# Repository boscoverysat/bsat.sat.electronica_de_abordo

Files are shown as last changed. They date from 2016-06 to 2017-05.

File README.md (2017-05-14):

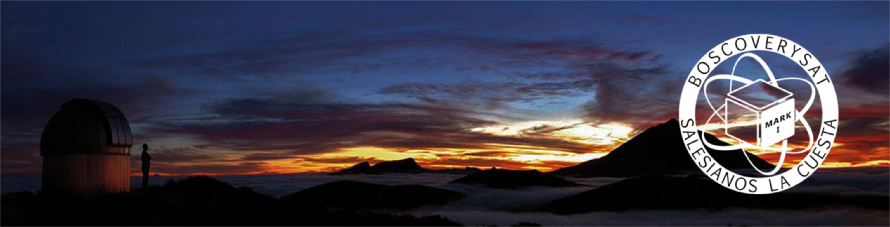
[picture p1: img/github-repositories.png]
Github header


# SAT Electrónica de Abordo

### Este repositorio ha sido descontinuado.

La información relativa a los elementos electrónicos del satélite podrán encontrarse en los siguientes enlaces:

- [Onboard Computer (OBC)](https://github.com/boscoverysat/bsat.sat.electronica.onboard_computer)
- [Electric Power System (EPS)](https://github.com/boscoverysat/bsat.sat.electronica.electric_power_system)
- [Communications (COMM)](https://github.com/boscoverysat/bsat.sat.electronica.communications)
- [Librerías](https://github.com/boscoverysat/bsat.sat.electronica.librerias)

### Licencia

Creaive Commons 4.0 logo (http://creativecommons.org/licenses/by-nc-sa/4.0/)

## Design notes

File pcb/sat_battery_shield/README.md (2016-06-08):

# SAT Battery Shield

## Resumen

Esta sección del repositorio contiene el circuito electrónico y el diseño de placa de circuito impreso para el sistema de alimentación del satélite.

El actual diseño electrónico se ha llevado a cabo mediante el software **KiCAD**.

## Contenido de la Shield

La PCB cuanta con unas dimensiones de 77 x 77 mm, realizada en base de fibra de vidrio y una única capa de cobre, disponiendo de cuatro orificios
de fijación, para el chasis del satélite, ubicados en las esquinas de la placa.

Actualmente, el diseño de este elemento se encuentra desarrollado para que sea capaz de alojar dos baterías recargables del tipo `18650`, por una tensión
nominal de **3,7V** y una intensidad de **5.000mAh**.

La placa tiene capacidad para conectar a ella cuatro parejas de placas solares, conectadas en serie entre ellas y posteriormente en paralelo en la propia
PCB. Esto nos permite contar con niveles de tensión de entre 8VDC y 11,50VDC, con una intensidad máxima de 50 mA, cada pareja de placas solares.

Para el sistema de recarga de baterías y alimentación de la electrónica de abordo, se han implementado dos módulos de recarga de baterías basados en
el circuito **TP4056**.

El objetivo de emplear este tipo de dispositivo era el de conectarlos en serie para poder proporcionar energía suficiente a la electrónica del satélite.

Además de lo indicado hasta el momento, la placa cuenta con un interruptor que nos permite encender y apagar el satélite de manera manual. En un futuro,
esta funcionalidad será empleada para implementar el sistema **RBF** ( *Remove Before Flight* ) así como los sistemas de conexión en el momento del
despliegue del satélite.

## Fallos detectados

Actualmente tenemos un fallo de alimentación dado que, una vez conectados los módulos `TP4056`, el segundo de ellos, al detectar un nivel de tensión
superior a los 4VDC en la salida del mismo (nivel proveniente del primer módulo que está conectado en serie con éste), deja de funcionar, proporcionando
a la salida de la placa, un nivel de tensión correspondiente al proporcionado únicamente por una de las baterías.

## Propuestas de mejora

- Rediseñar la electrónica de la placa con el objeto de implementar reguladores de tensión basados en los dispositivos **78L09** así como en el regulador de carga **MAX1873**.
- Proporcionar lineas de test para el registro del nivel de tensión proporcionado por las caras del satélite.
- Proporcionar lineas de test para el registro del nivel de tensión disponible en cada una de las baterías.

#### Diseño PCB

Diseño de PCB

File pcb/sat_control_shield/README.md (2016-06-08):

# SAT Control Shield

## Resumen

Esta sección del repositorio contiene el circuito electrónico y el diseño de placa de circuito impreso para el sistema de control del satélite.

El actual diseño electrónico se ha llevado a cabo mediante el software **KiCAD** e incluye en una misma placa, el núcleo de procesamiento del
satélite (formado por un Arduino Nano v3.0), los sensores de inercia y orientación, así como un único sensor de temperatura, los pines necesarios
para la conexión de cuatro sensores de intensidad luminosa y el módulo de transmisión RF a 433MHz.

## Contenido actual de la Shield

La PCB cuenta con unas dimensiones de 77 x 77 mm, realizada en base de fibra de vidrio y una única capa de cobre, disponiendo de cuatro orificios
de fijación, para el chasis del satélite, ubicados en las esquinas de la placa.

Actualmente la placa cuenta con una alimentación simple que proviene desde la shield de alimentación. De este modo, a la entrada de la placa disponemos
de un nivel de tensión de entre 7,5VDC y 8,4VDC, dependiendo del nivel de carga que tengan las baterías.

Con este nivel de voltaje se proporciona energía directamente a la unidad de control del satélite, formada por el Arduino Nano v3.0. A partir de él,
empleamos las salidas estabilizadas de 5VDC y 3,3VDC para alimentar al resto de elementos del circuito.

De este modo, el giroscopico (`HPU6000`), el acelerómetro (`HMC5883L`), el sensor de temperatura (`HTU21D`) y los sensores de luminosidad (`BH1750`) se
encuentran alimentados a 3,3VDC.

Por otro lado, el transmisor de RF (`CDT-88`) y el multiplexor de I2C (`74HC4052E`) se encuentran alimentados a 5VDC.

Todos los sensores presentes en la placa, se comunican con el Arduino a través del bus I2C. Por esta razón y dado que en el diseño se emplean múltiple
sensores del mismo modelo que vienen con la dirección de comunicación fijada por hardware, ha sido necesario emplear el circuito integrado `74HC4052E`,
encargado de multiplexar la señal SDA del I2C.

**NOTA:** La **multiplexación** de la señal **SDA** del bus **I2C** mediante el circuito integrado `74HC4052E` aún se encuentra en **fase experimental**.

## Fallos detectados

Aún no se han detectado fallos para el diseño actual.

## Propuestas de mejora

- Confirmar el correcto funcionamiento de la multiplexación del canal SDA del bus I2C mediante el uso del circuito integrado `74HC4052E`.
- Multiplexar la señal SDA para los sensores de intensidad luminosa.
- Multiplexar la señal SDA para los sensores de temperatura.
- Obtener lecturas de los niveles de tensión proporcionados por las placas solares dispuestas en las caras del satélite.
- Obtener lecturas de los niveles de tensión proporcionados por las baterías del sistema de alimentación.

#### Diseño PCB

Diseño de PCB

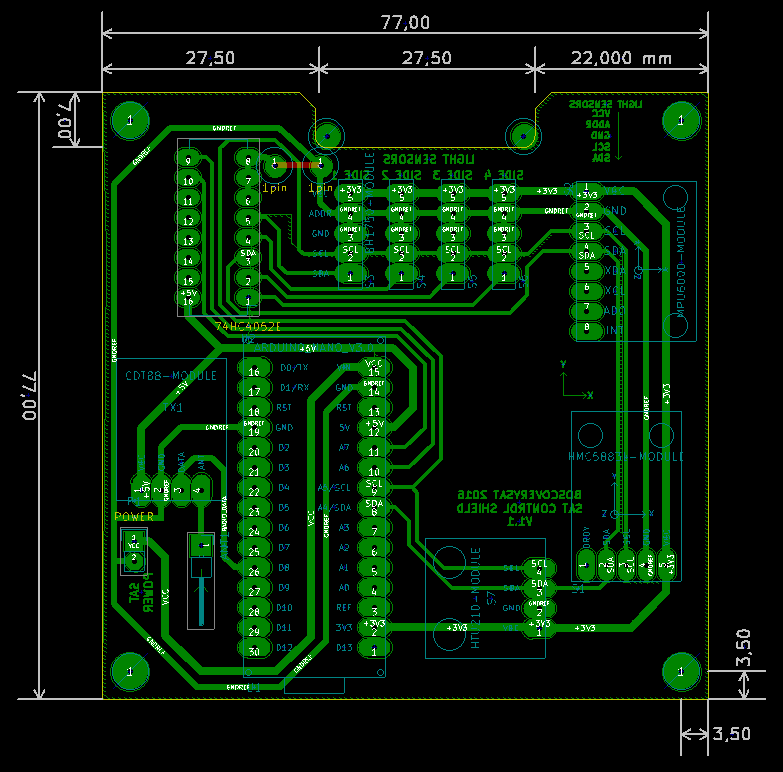
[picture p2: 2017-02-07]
pcb/sat_control_shield/img/Sat Control Shield - PCB - v2.0.png

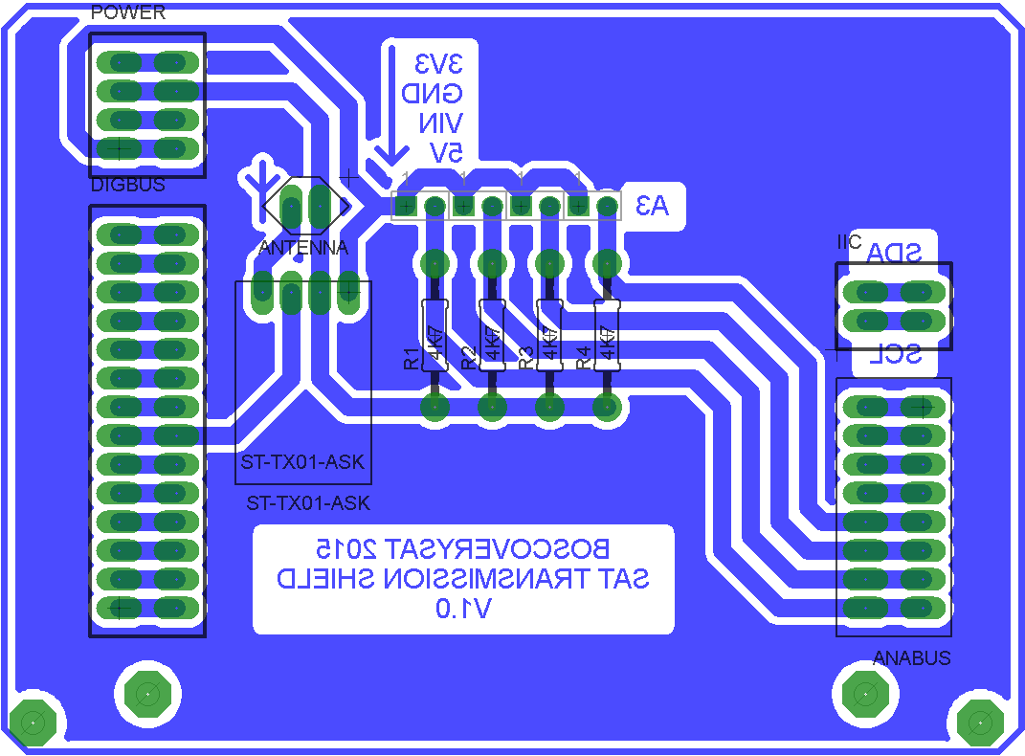
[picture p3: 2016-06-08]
pcb/sat_transmission_shield/img/sat_transmission_shield.png

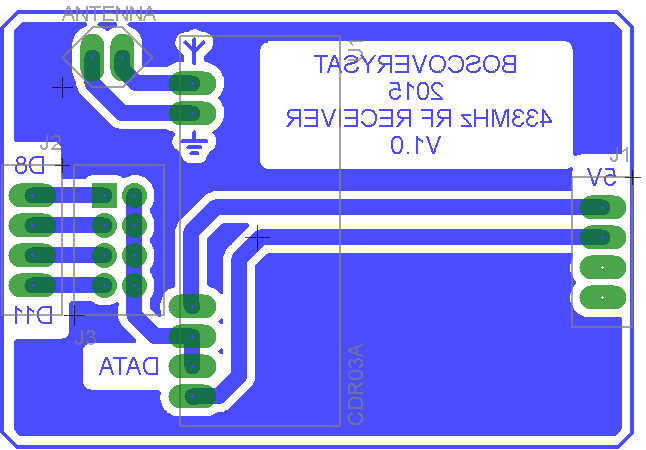
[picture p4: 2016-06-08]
pcb/receptor_rf_430mhz/img/430mhz_rf_receiver.png

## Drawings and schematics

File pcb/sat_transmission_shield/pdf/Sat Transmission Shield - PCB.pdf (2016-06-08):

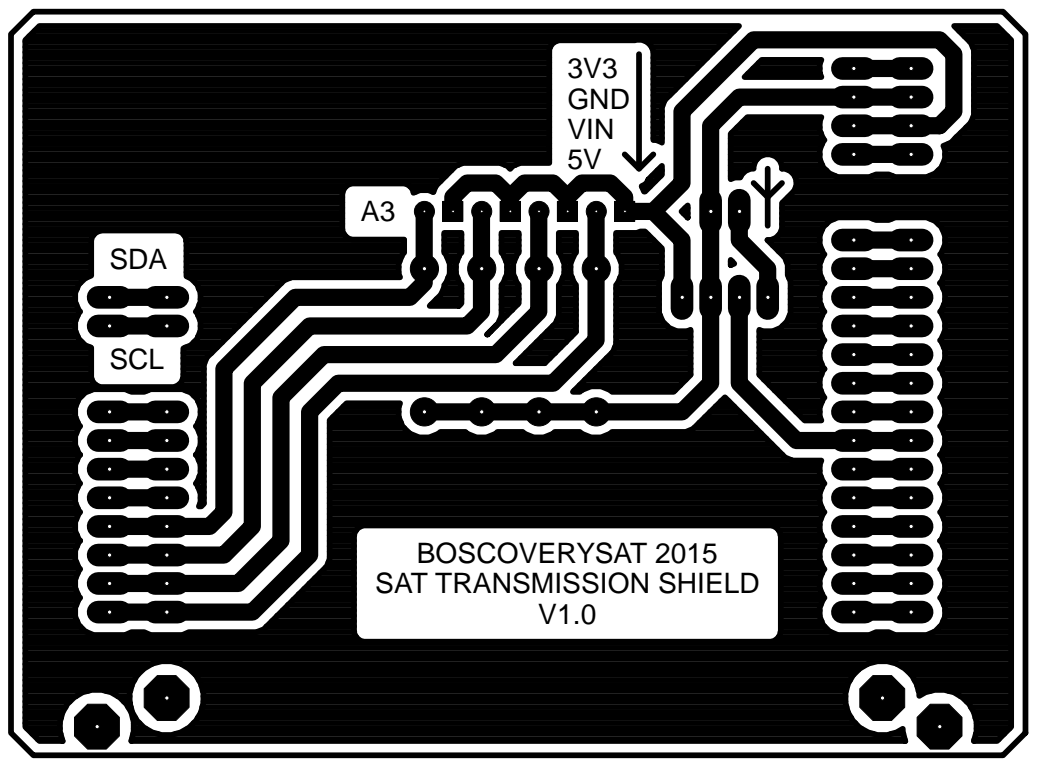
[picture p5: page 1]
3V3 GND VIN 5V; SCL; SDA

BOSCOVERYSAT 2015
SAT TRANSMISSION SHIELD

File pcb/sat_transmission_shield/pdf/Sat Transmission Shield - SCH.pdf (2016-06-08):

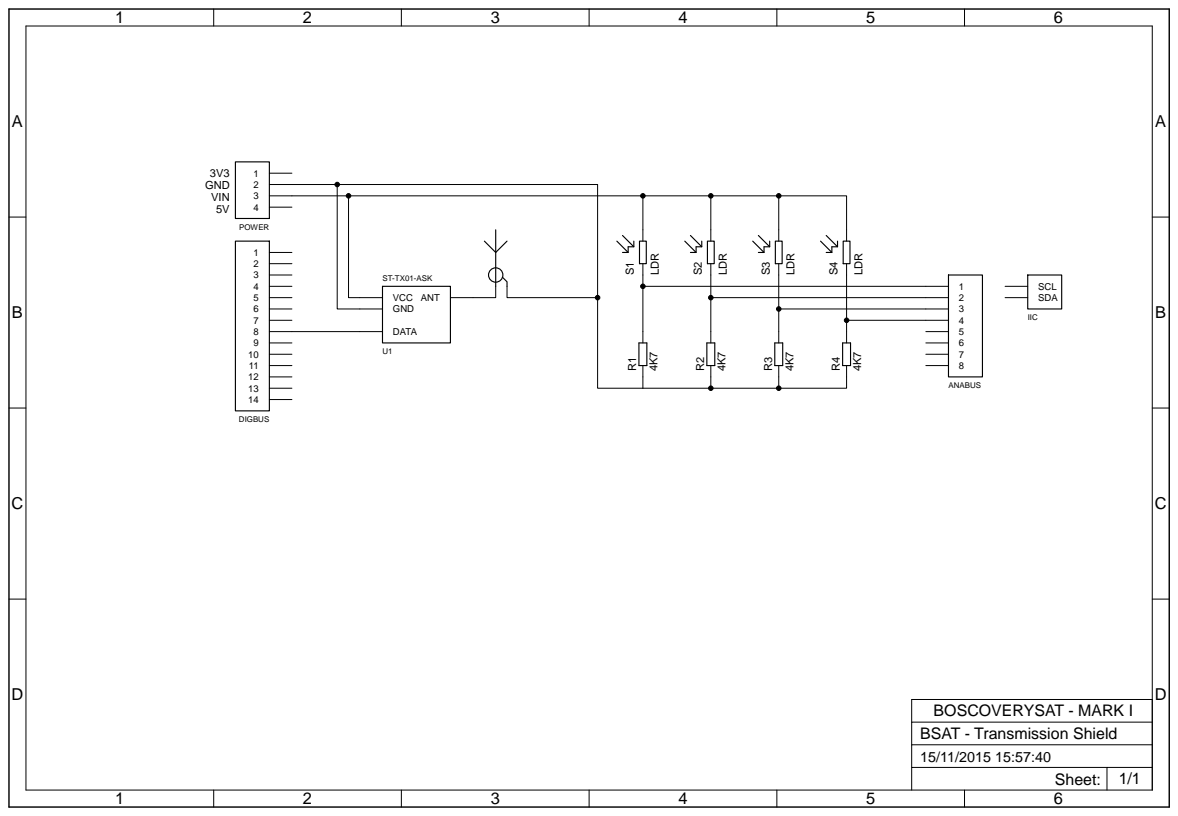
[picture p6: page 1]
3V3 GND VIN 5V; ST-TX01-ASK; LDR 4K7; DIGBUS; POWER; SCL SDA; IIC; VCC GND; DATA; ANT; ANABUS; Sheet: 1/1

BOSCOVERYSAT - MARK I
BSAT - Transmission Shield

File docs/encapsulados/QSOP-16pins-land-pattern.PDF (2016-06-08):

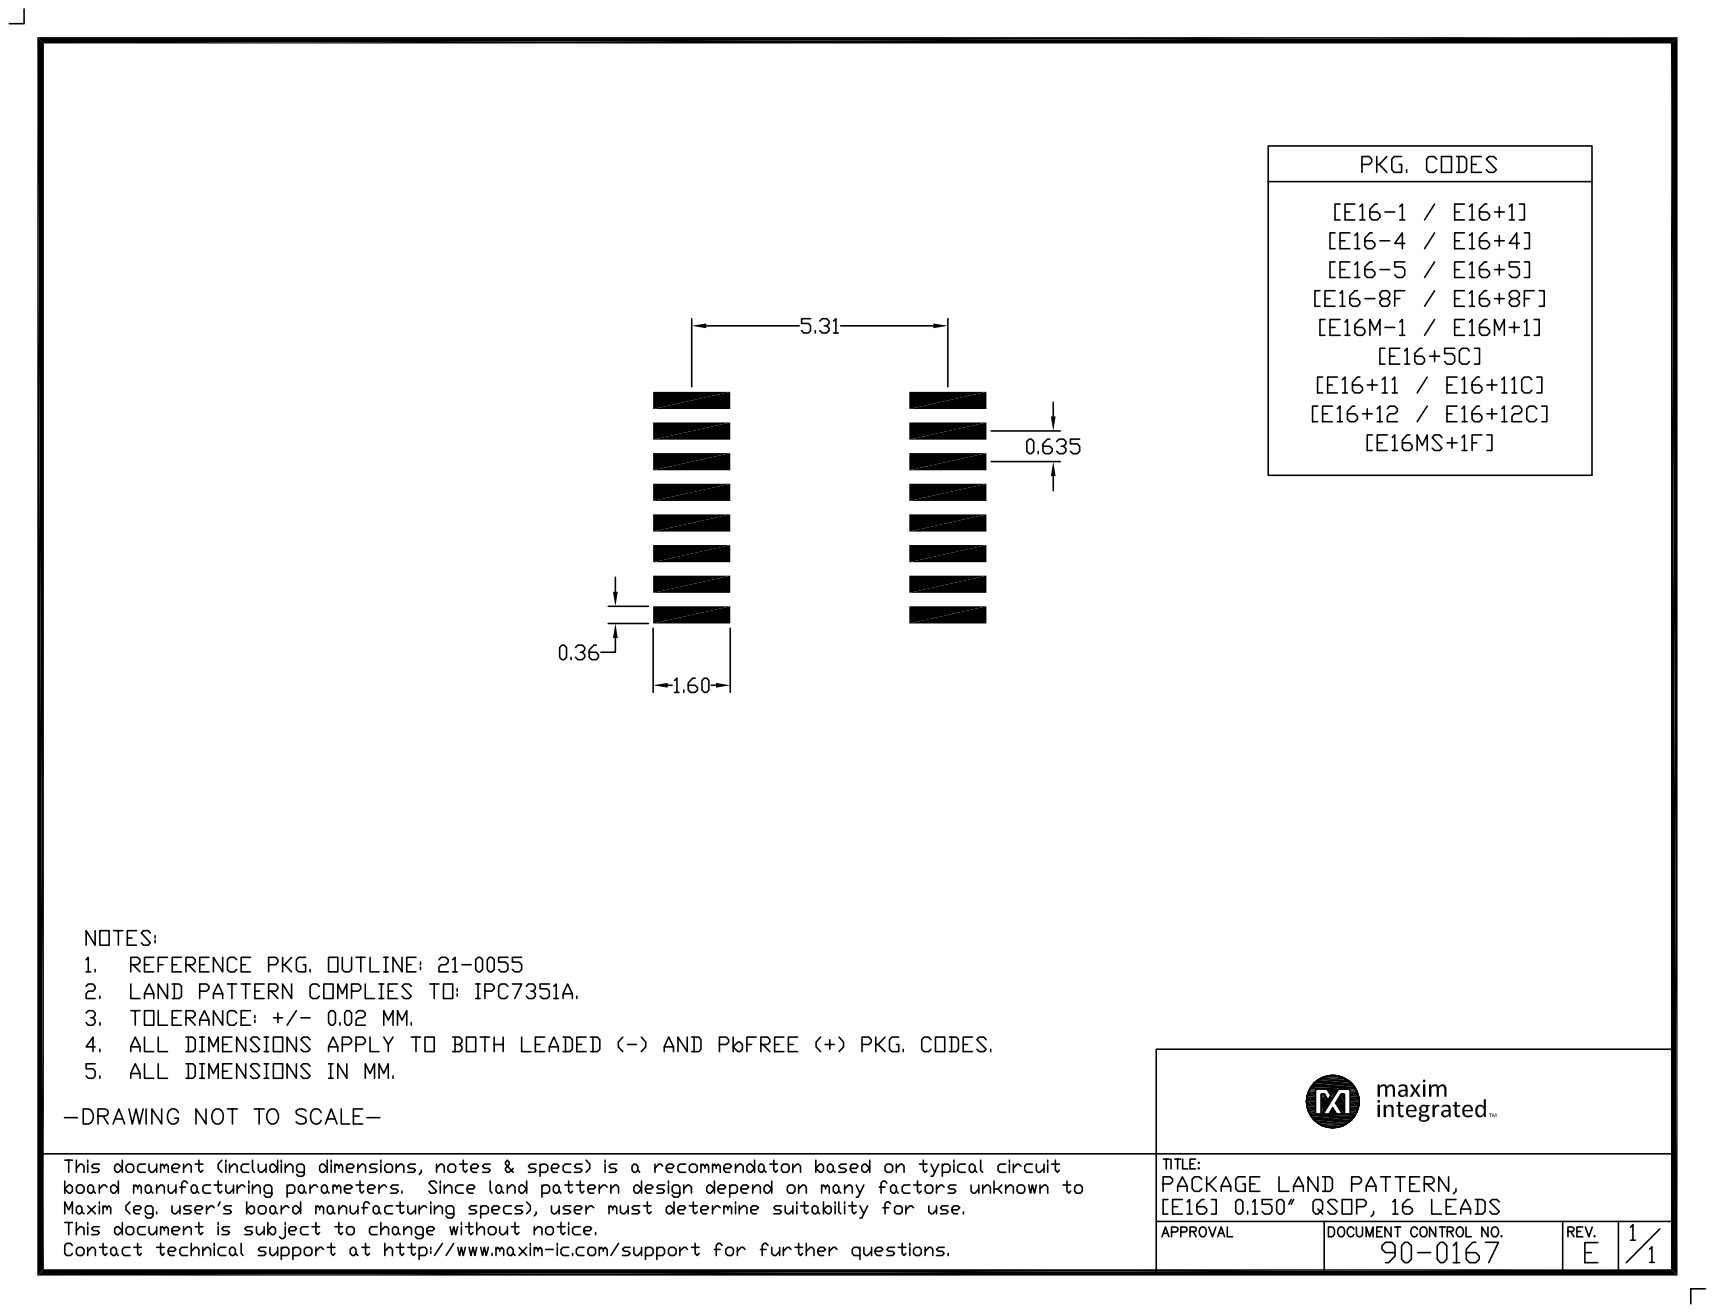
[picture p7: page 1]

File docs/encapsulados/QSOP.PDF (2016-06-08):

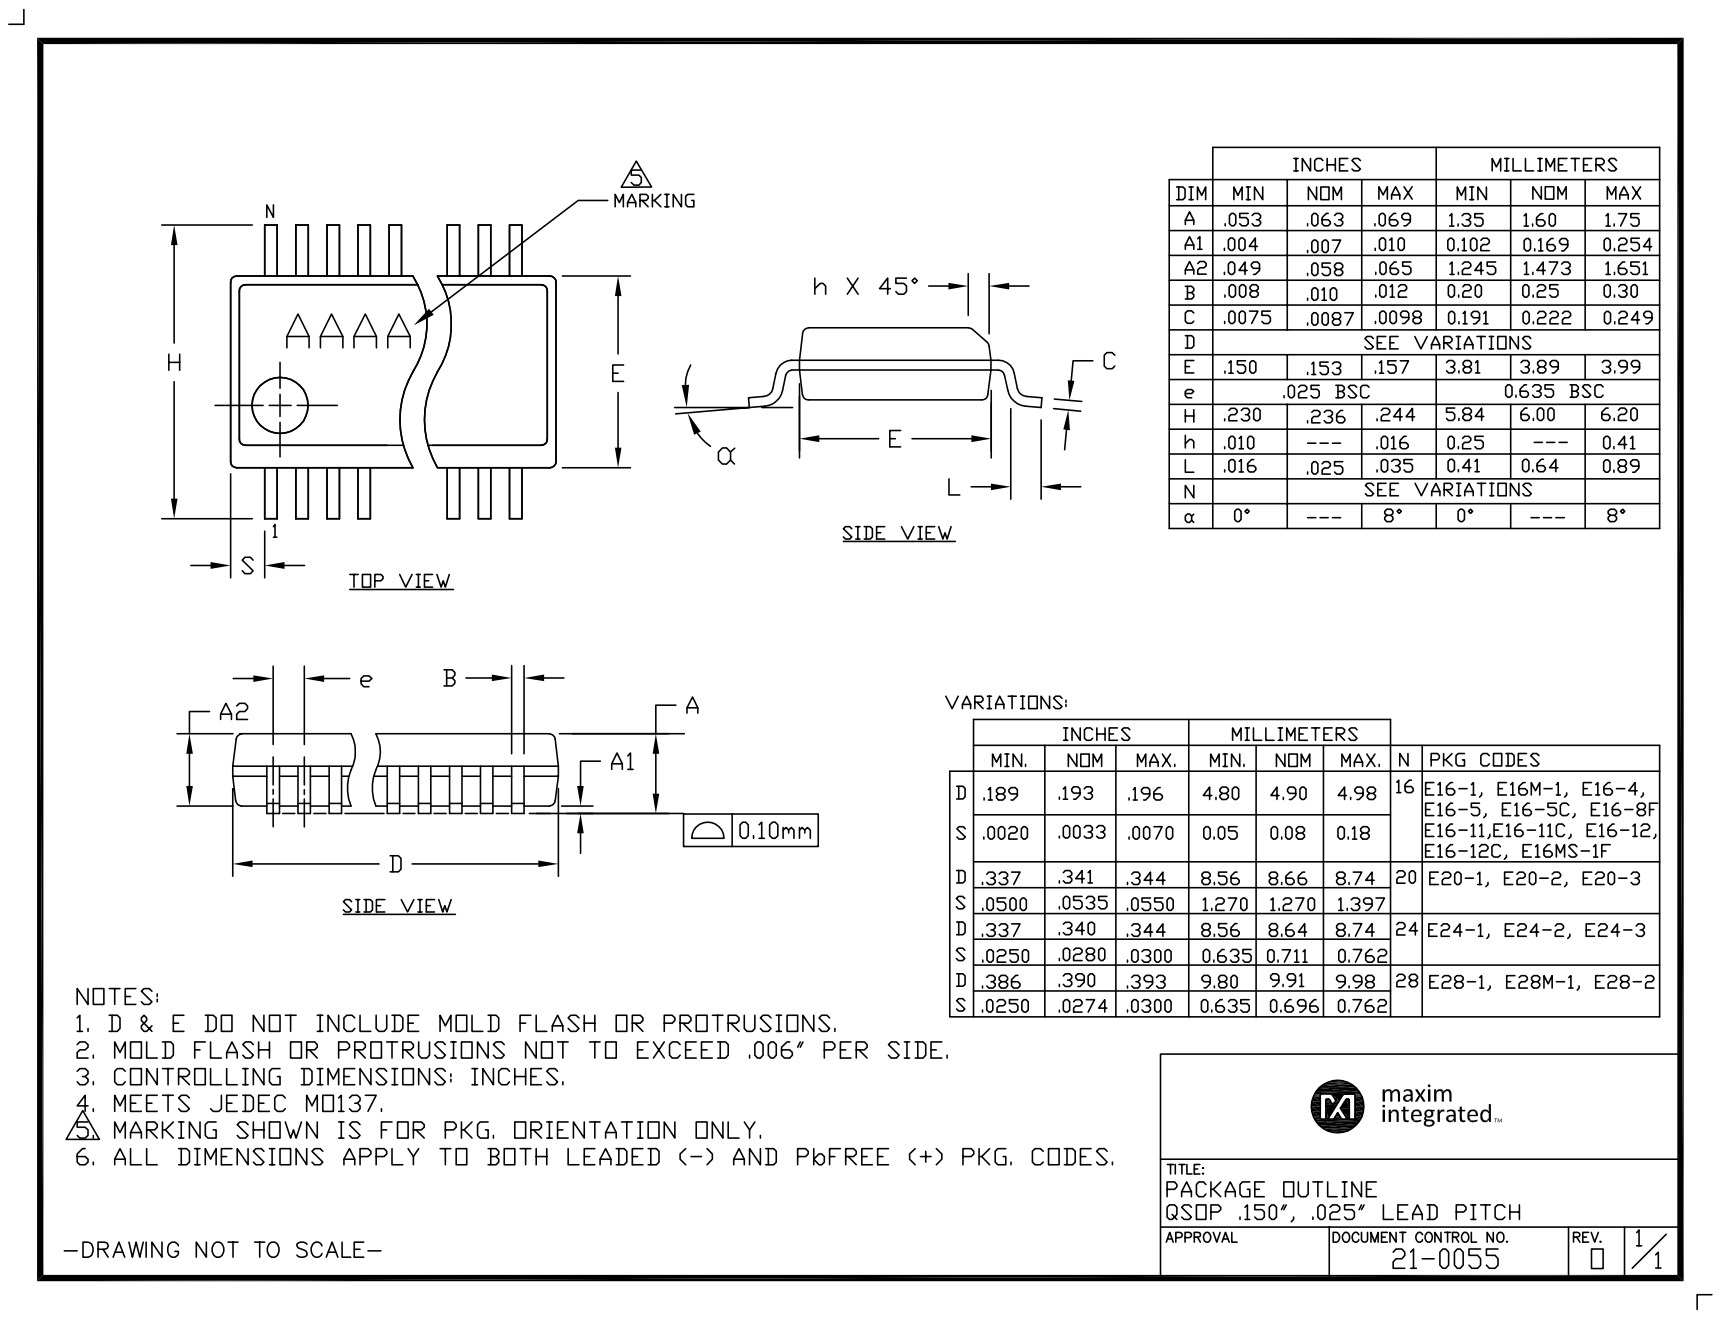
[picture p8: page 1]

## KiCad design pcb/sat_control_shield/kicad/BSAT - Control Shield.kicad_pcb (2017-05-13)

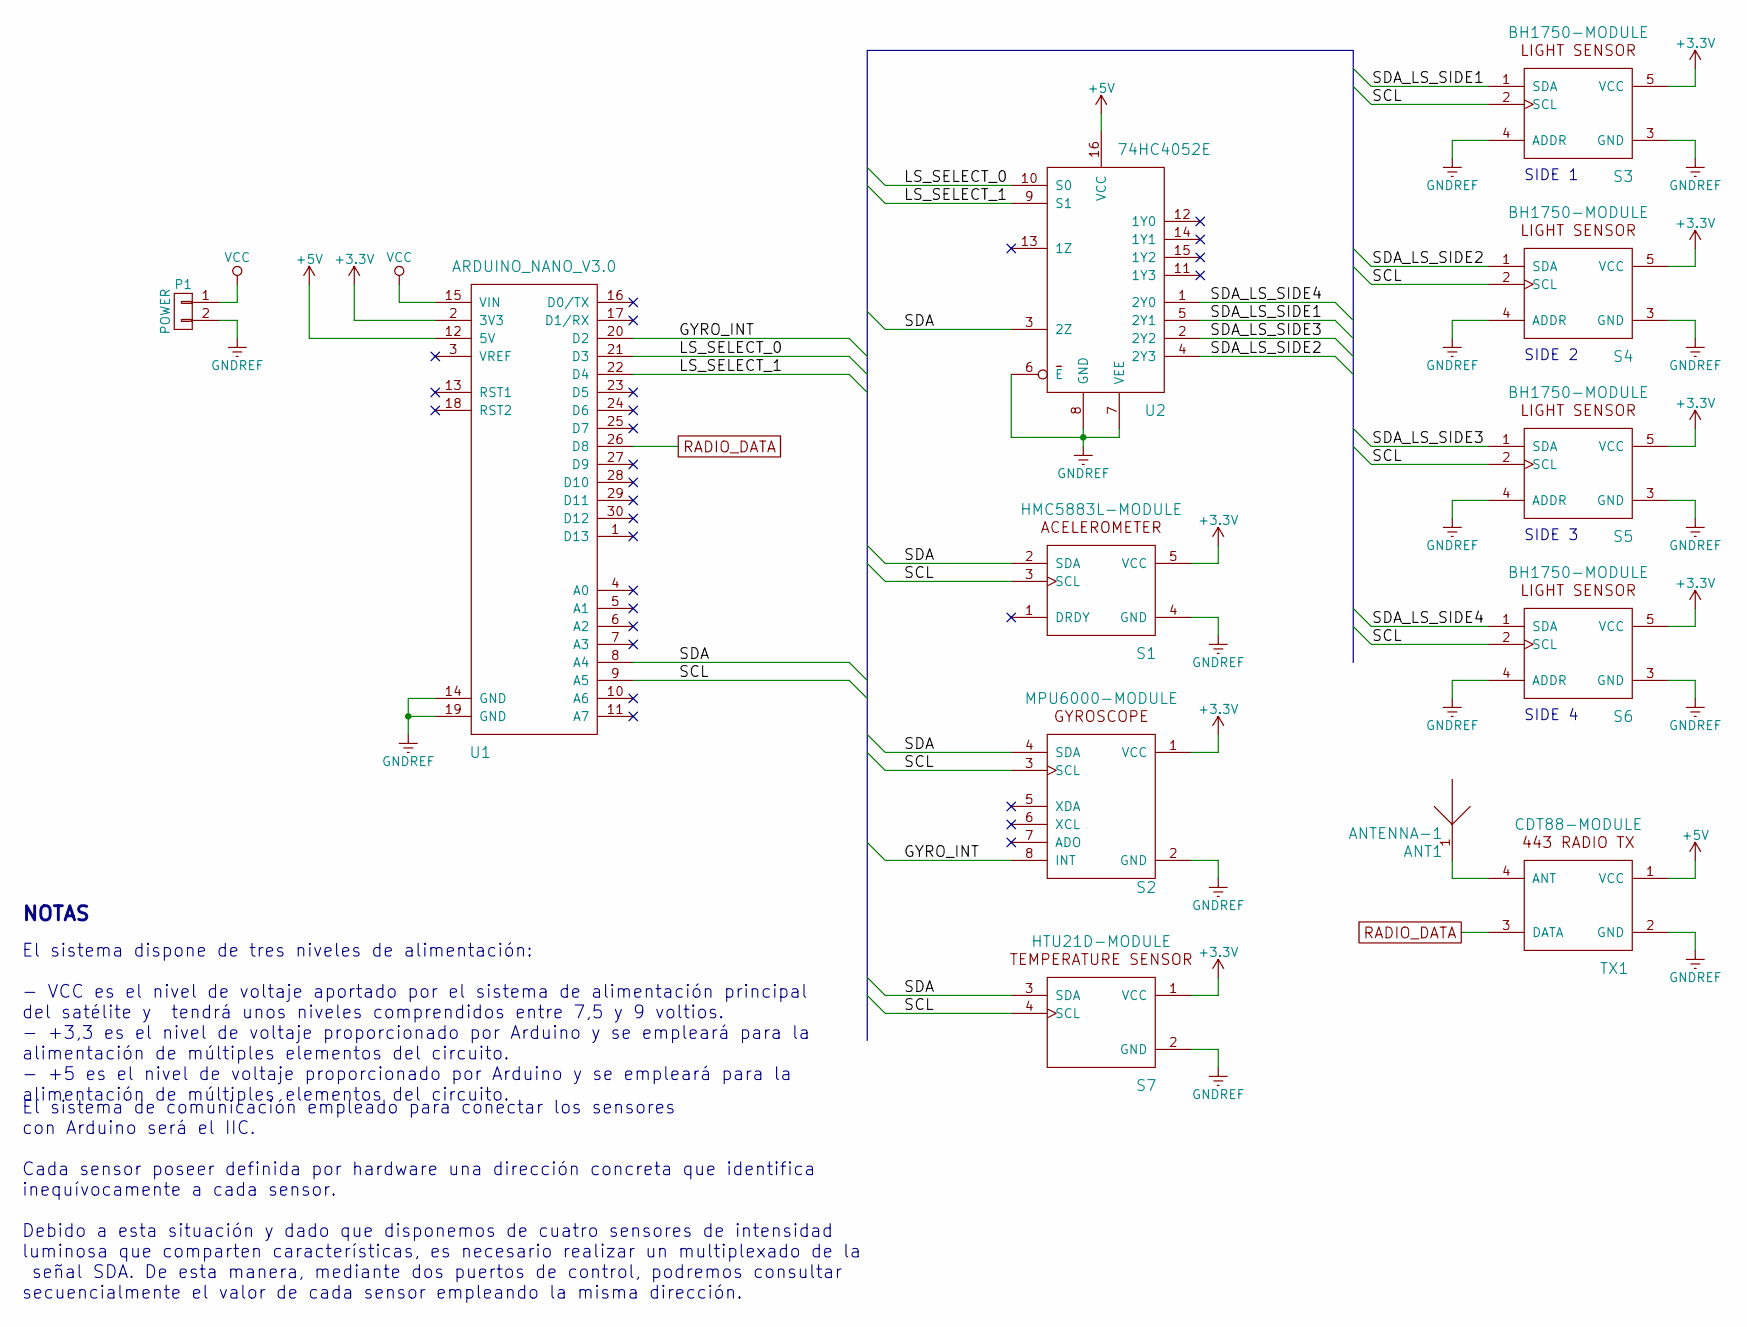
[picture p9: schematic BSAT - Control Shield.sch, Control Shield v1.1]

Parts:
ANT1: ANTENNA-1; Pin_Header_Angled_1x01_Pitch2.54mm
P1: POWER; Pin_Header_Straight_1x02_Pitch2.54mm
S1: HMC5883L-MODULE; HMC5883L
S2: MPU6000-MODULE; MPU-6000
S3, S4, S5, S6: BH1750-MODULE
S7: HTU21D-MODULE
TX1: CDT88-MODULE; CDT-88
U1: ARDUINO_NANO_V3.0
U2: 74HC4052E; DIP-16_W7.62mm_LongPads

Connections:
+3V3: S1.5 (VCC), S2.1 (VCC), S3.5 (VCC), S4.5 (VCC), S5.5 (VCC), S6.5 (VCC), S7.1 (VCC), U1.2 (3V3)
+5V: TX1.1 (VCC), U1.12 (5V), U2.16 (VCC)
/GYRO_INT: S2.8 (INT), U1.20 (D2)
/LS_SELECT_0: U1.21 (D3), U2.10 (S0)
/LS_SELECT_1: U1.22 (D4), U2.9 (S1)
/SCL: S1.3 (SCL), S2.3 (SCL), S3.2 (SCL), S4.2 (SCL), S5.2 (SCL), S6.2 (SCL), S7.4 (SCL), U1.9 (A5)
/SDA: S1.2 (SDA), S2.4 (SDA), S7.3 (SDA), U1.8 (A4), U2.3 (2Z)
/SDA_LS_SIDE1: S3.1 (SDA), U2.5 (2Y1)
/SDA_LS_SIDE2: S4.1 (SDA), U2.4 (2Y3)
/SDA_LS_SIDE3: S5.1 (SDA), U2.2 (2Y2)
/SDA_LS_SIDE4: S6.1 (SDA), U2.1 (2Y0)
GNDREF: P1.2, S1.4 (GND), S2.2 (GND), S3.3 (GND), S3.4 (ADDR), S4.3 (GND), S4.4 (ADDR), S5.3 (GND), S5.4 (ADDR), S6.3 (GND), S6.4 (ADDR), S7.2 (GND), TX1.2 (GND), U1.14 (GND), U1.19 (GND), U2.6 (E), U2.7 (VEE), U2.8 (GND)
unnamed: ANT1.1, TX1.4 (ANT)
RADIO_DATA: TX1.3 (DATA), U1.26 (D8)
VCC: P1.1, U1.15 (VIN)

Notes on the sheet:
SIDE 1
SIDE 2
SIDE 3
SIDE 4
NOTAS
El sistema dispone de tres niveles de alimentación: - VCC es el nivel de voltaje aportado por el sistema de alimentación principal del satélite y tendrá unos niveles comprendidos entre 7,5 y 9 voltios. - +3,3 es el nivel de voltaje proporcionado por Arduino y se empleará para la alimentación de múl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
El sistema de comunicación empleado para conectar los sensores con Arduino será el IIC. Cada sensor poseer definida por hardware una dirección concreta que identifica inequívocamente a cada sensor. Debido a esta situación y dado que disponemos de cuatro sensores de intensidad luminosa que comparten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

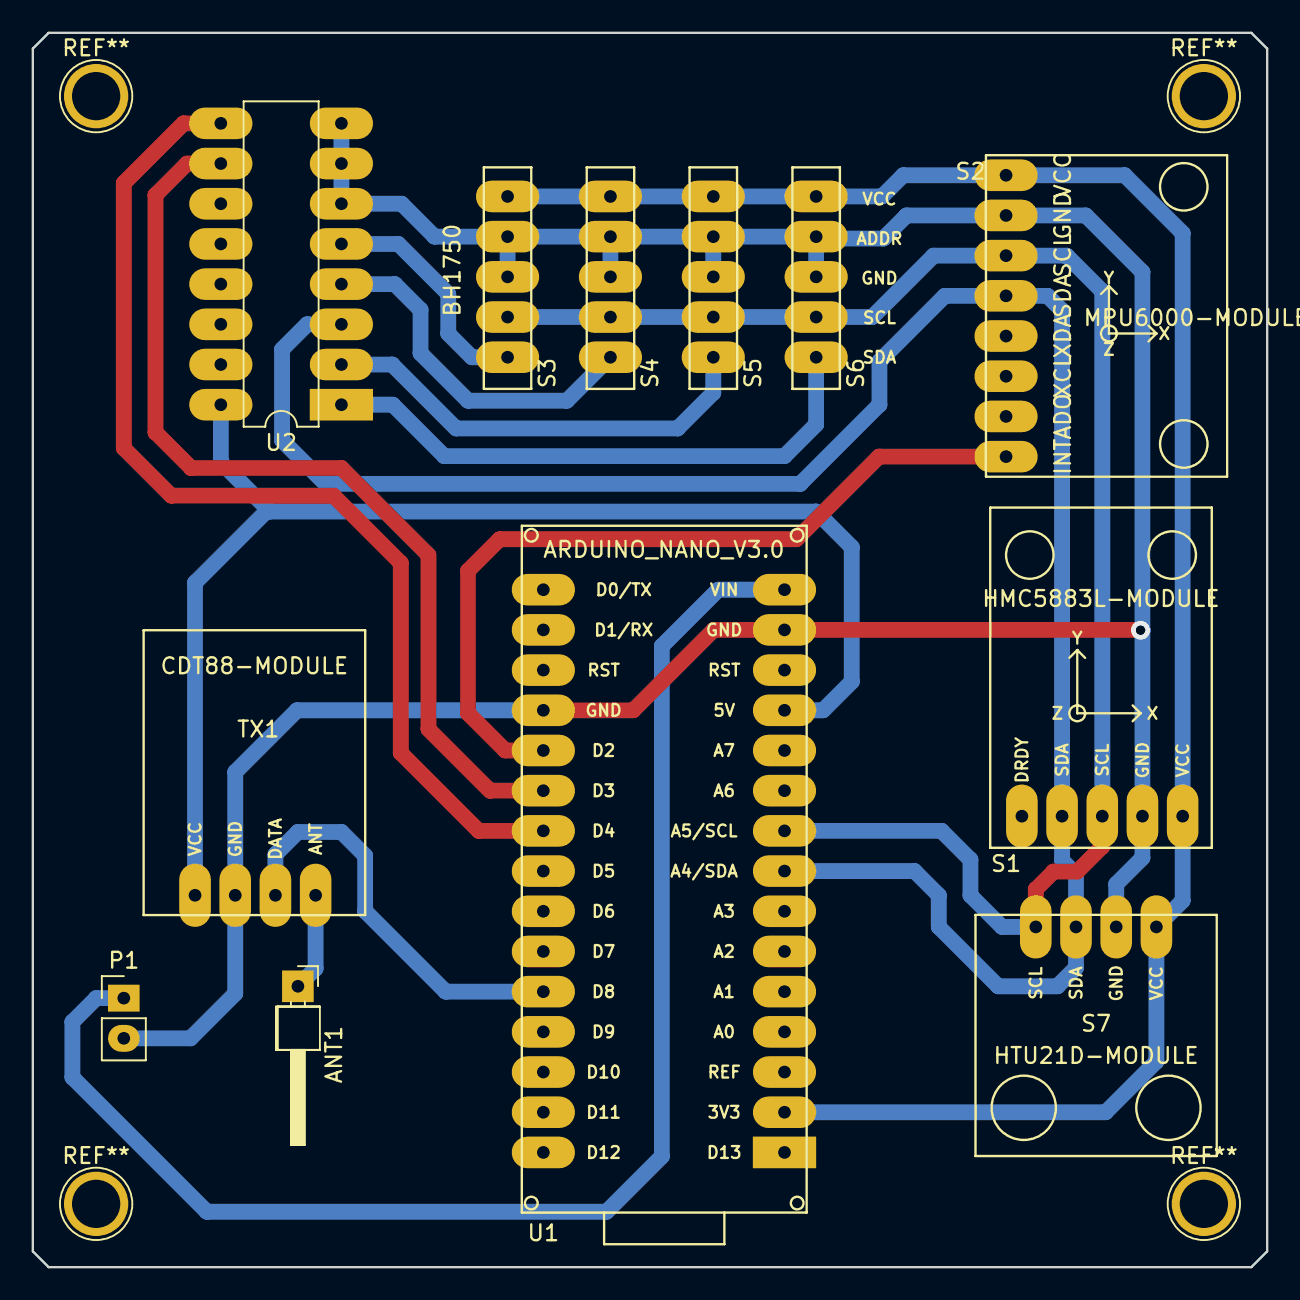
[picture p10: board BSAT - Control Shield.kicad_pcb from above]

Board: 2 copper layers, 78.0 x 78.0 mm, 12 parts (0 on the bottom side), 15 nets.

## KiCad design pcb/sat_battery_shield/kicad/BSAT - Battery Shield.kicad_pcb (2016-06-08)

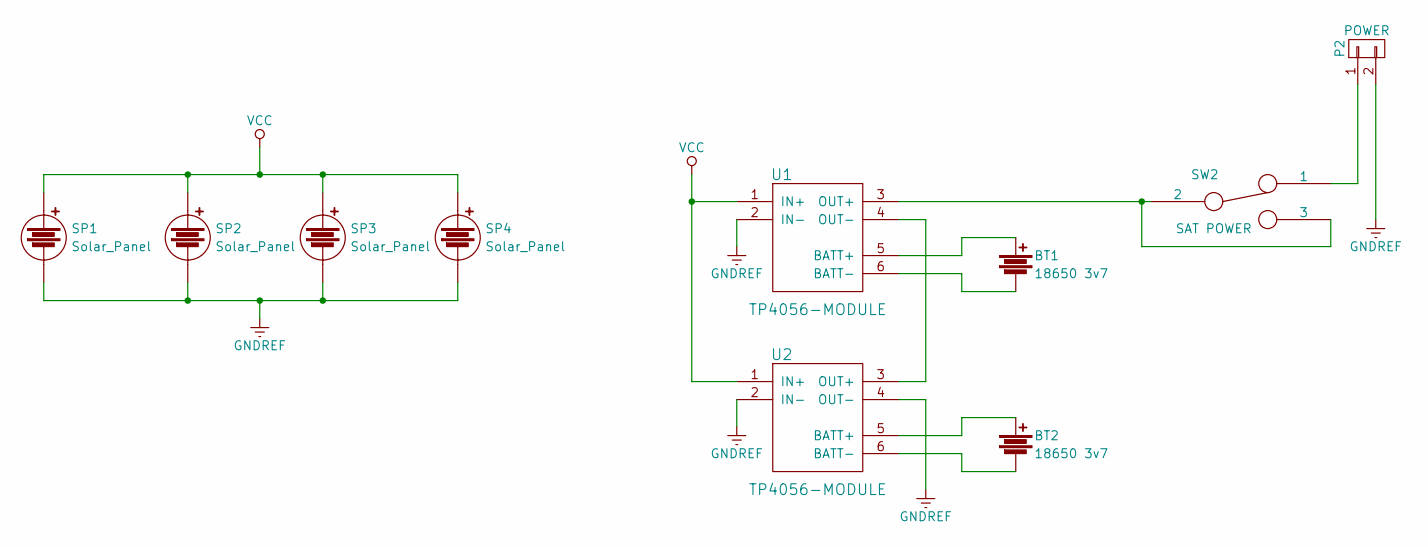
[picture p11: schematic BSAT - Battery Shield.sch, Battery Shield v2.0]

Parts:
BT1, BT2: 18650 3v7; BATT-18650
P2: POWER; Pin_Header_Straight_1x02
SP1, SP2, SP3, SP4: Solar_Panel; Pin_Header_Straight_1x02
SW2: SAT POWER; SWITCH-1CIR-2CON
U1, U2: TP4056-MODULE

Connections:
GNDREF: P2.2, SP1.2, SP2.2, SP3.2, SP4.2, U1.2 (IN-), U2.2 (IN-), U2.4 (OUT-)
unnamed: BT1.1, U1.5 (BATT+)
unnamed: BT1.2, U1.6 (BATT-)
unnamed: BT2.1, U2.5 (BATT+)
unnamed: BT2.2, U2.6 (BATT-)
unnamed: P2.1, SW2.1
unnamed: SW2.2, SW2.3, U1.3 (OUT+)
unnamed: U1.4 (OUT-), U2.3 (OUT+)
VCC: SP1.1, SP2.1, SP3.1, SP4.1, U1.1 (IN+), U2.1 (IN+)

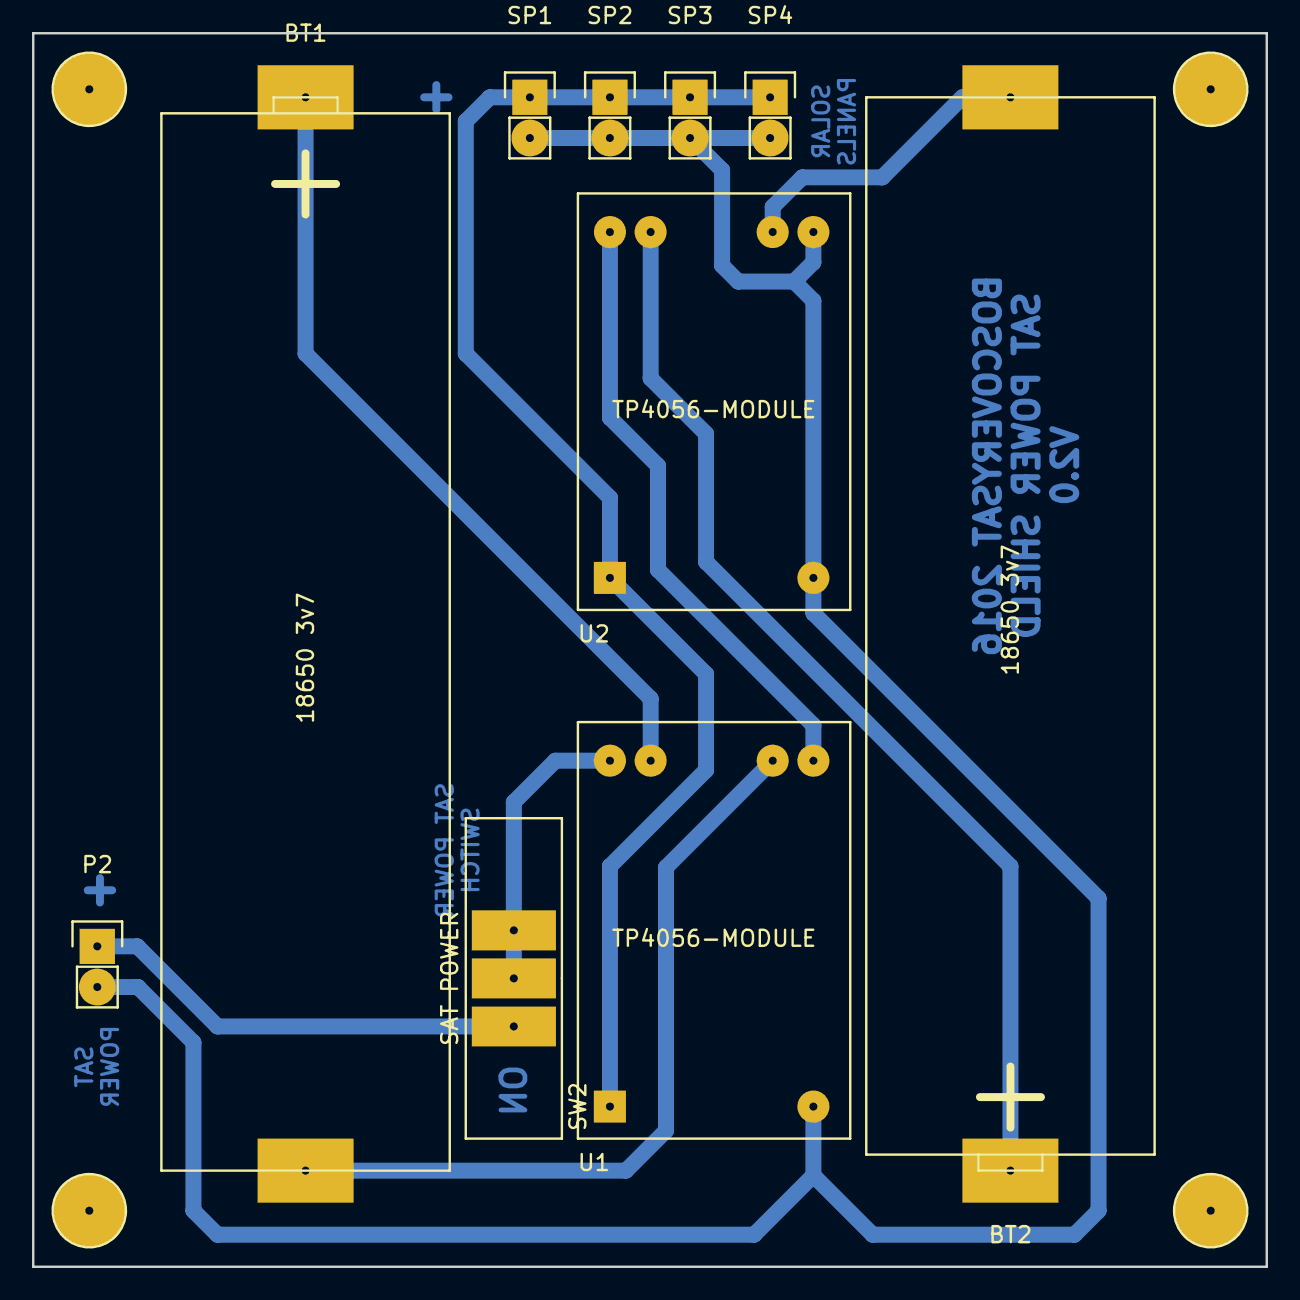
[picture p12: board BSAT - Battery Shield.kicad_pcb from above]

Board: 2 copper layers, 77.0 x 77.0 mm, 10 parts (0 on the bottom side), 9 nets.

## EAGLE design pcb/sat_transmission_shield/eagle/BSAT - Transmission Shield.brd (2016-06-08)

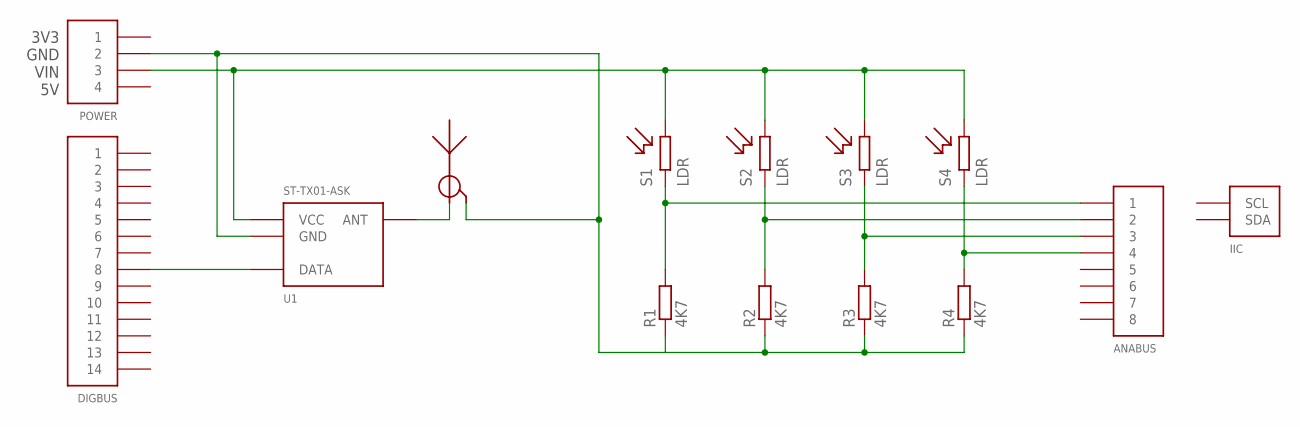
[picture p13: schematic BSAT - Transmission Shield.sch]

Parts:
ANABUS: 8-PIN-DUAL-BUS
DIGBUS: 14-PIN-DUAL-BUS
IIC: IIC-DUAL-BUS; 2-PIN-DUAL-BUS
POWER: 4-PIN-DUAL-BUS; 4-PIN-LINEAL-JUMPER
R1, R2, R3, R4: 4K7; 0207/12
S1, S2, S3, S4: LDR; 2-PIN-JUMPER
U1: ST-TX01-ASK
U$5: ANTENNA

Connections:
unnamed: ANABUS.1A (1), ANABUS.1B (1), R1.2, S1.P$2 (2)
unnamed: ANABUS.2A (2), ANABUS.2B (2), R2.2, S2.P$2 (2)
unnamed: ANABUS.3A (3), ANABUS.3B (3), R3.2, S3.P$2 (2)
unnamed: ANABUS.4A (4), ANABUS.4B (4), R4.2, S4.P$2 (2)
unnamed: POWER.3A (3), POWER.3B (3), S1.P$1 (1), S2.P$1 (1), S3.P$1 (1), S4.P$1 (1), U1.VCC
unnamed: DIGBUS.8A (8), DIGBUS.8B (8), U1.DATA
unnamed: POWER.2A (2), POWER.2B (2), R1.1, R2.1, R3.1, R4.1, U1.GND, U$5.GANT
unnamed: U1.ANT, U$5.ANT

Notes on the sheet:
3V3 GND VIN 5V

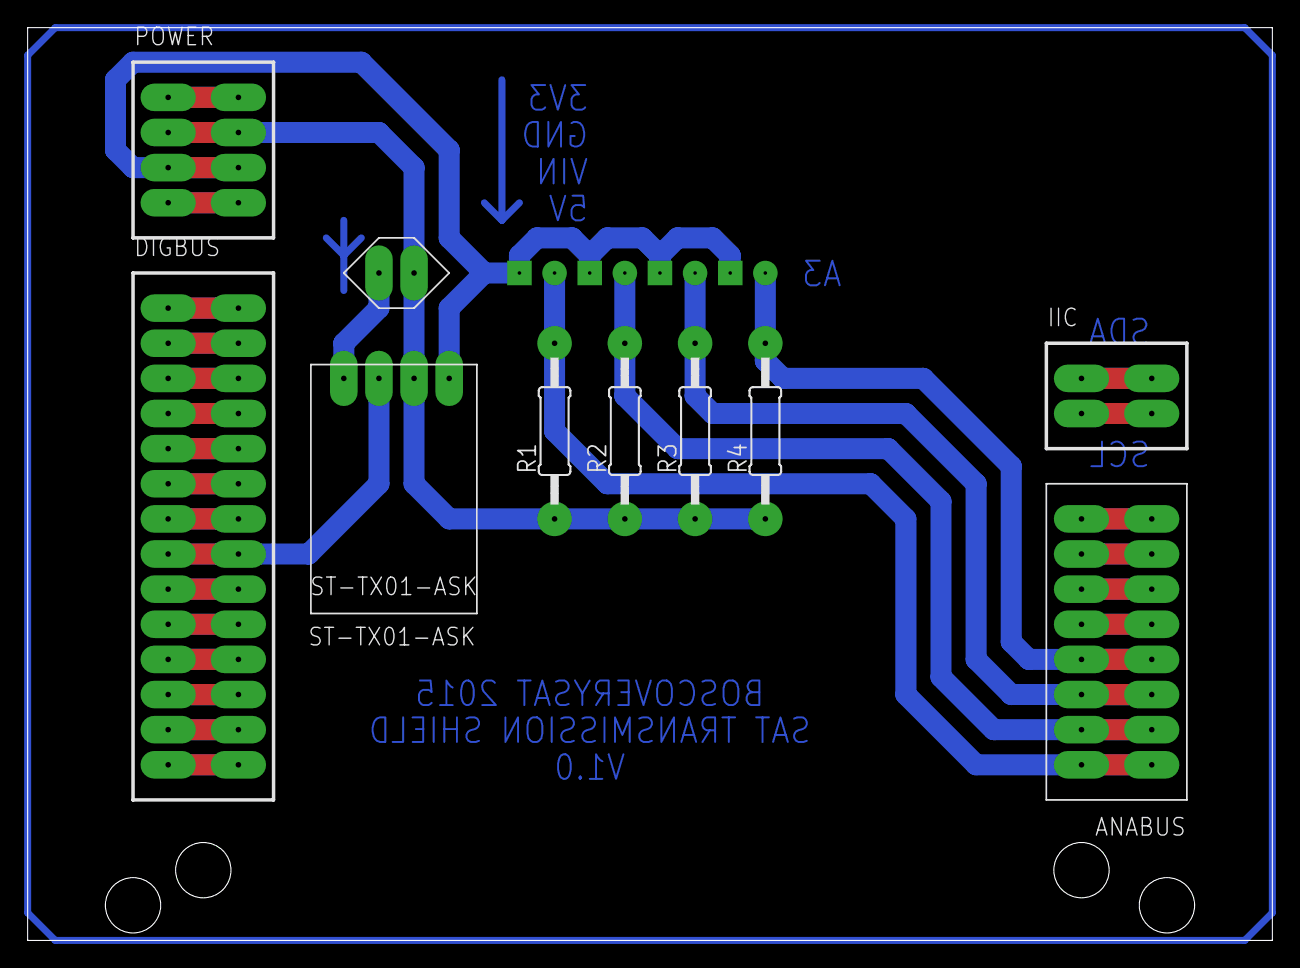
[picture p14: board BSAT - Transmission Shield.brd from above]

Board: 2 copper layers, 90.0 x 66.0 mm, 14 parts (0 on the bottom side), 8 nets.

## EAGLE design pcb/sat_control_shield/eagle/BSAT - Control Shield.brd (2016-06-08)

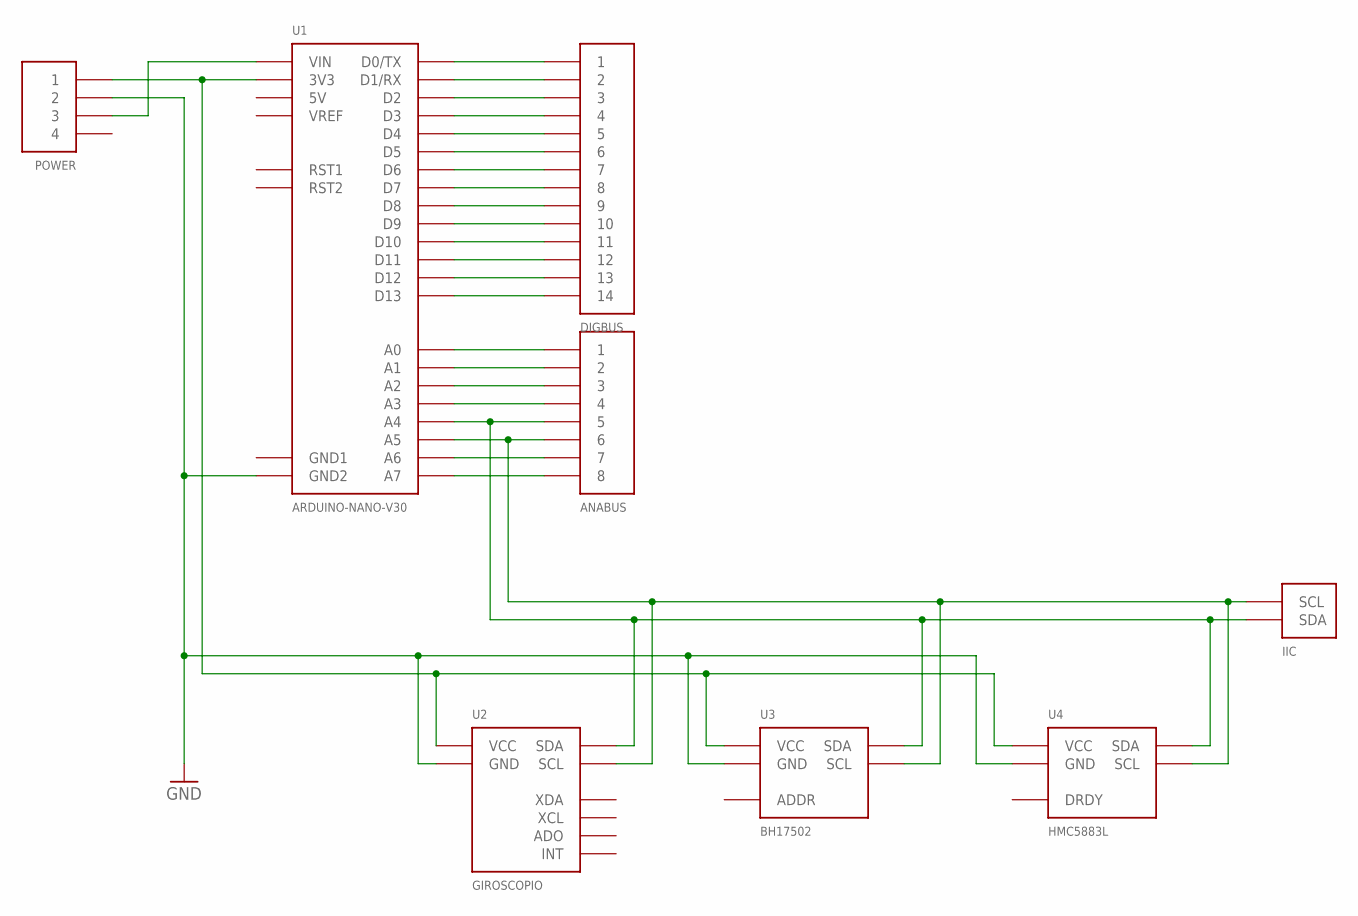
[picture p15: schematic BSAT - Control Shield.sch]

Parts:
ANABUS: 8-PIN-DUAL-BUS
DIGBUS: 14-PIN-DUAL-BUS
IIC: IIC-DUAL-BUS; 2-PIN-DUAL-BUS
POWER: 4-PIN-DUAL-BUS; 4-PIN-LINEAL-JUMPER
U1: ARDUINO-NANO-V30
U2: GIROSCOPIO
U3: BH17502; BH1750-2
U4: HMC5883L

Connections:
5V: U1.5V
GND: POWER.2A (2), POWER.2B (2), U1.GND2, U2.GND, U3.GND, U4.GND
GND1: U1.GND1
unnamed: DIGBUS.1A (1), DIGBUS.1B (1), U1.D0/TX
unnamed: DIGBUS.2A (2), DIGBUS.2B (2), U1.D1/RX
unnamed: POWER.3A (3), POWER.3B (3), U1.VIN
unnamed: POWER.1A (1), POWER.1B (1), U1.3V3, U2.VCC, U3.VCC, U4.VCC
unnamed: ANABUS.8A (8), ANABUS.8B (8), U1.A7
unnamed: ANABUS.7A (7), ANABUS.7B (7), U1.A6
unnamed: ANABUS.6A (6), ANABUS.6B (6), IIC.2A (SCL), IIC.2B (SCL), U1.A5, U2.SCL, U3.SCL, U4.SCL
unnamed: ANABUS.5A (5), ANABUS.5B (5), IIC.1A (SDA), IIC.1B (SDA), U1.A4, U2.SDA, U3.SDA, U4.SDA
unnamed: ANABUS.4A (4), ANABUS.4B (4), U1.A3
unnamed: ANABUS.3A (3), ANABUS.3B (3), U1.A2
unnamed: ANABUS.2A (2), ANABUS.2B (2), U1.A1
unnamed: ANABUS.1A (1), ANABUS.1B (1), U1.A0
unnamed: DIGBUS.3A (3), DIGBUS.3B (3), U1.D2
unnamed: DIGBUS.4A (4), DIGBUS.4B (4), U1.D3
unnamed: DIGBUS.5A (5), DIGBUS.5B (5), U1.D4
unnamed: DIGBUS.6A (6), DIGBUS.6B (6), U1.D5
unnamed: DIGBUS.7A (7), DIGBUS.7B (7), U1.D6
unnamed: DIGBUS.8A (8), DIGBUS.8B (8), U1.D7
unnamed: DIGBUS.9A (9), DIGBUS.9B (9), U1.D8
unnamed: DIGBUS.10A (10), DIGBUS.10B (10), U1.D9
unnamed: DIGBUS.11A (11), DIGBUS.11B (11), U1.D10
unnamed: DIGBUS.12A (12), DIGBUS.12B (12), U1.D11
unnamed: DIGBUS.13A (13), DIGBUS.13B (13), U1.D12
unnamed: DIGBUS.14A (14), DIGBUS.14B (14), U1.D13
VREF: U1.VREF

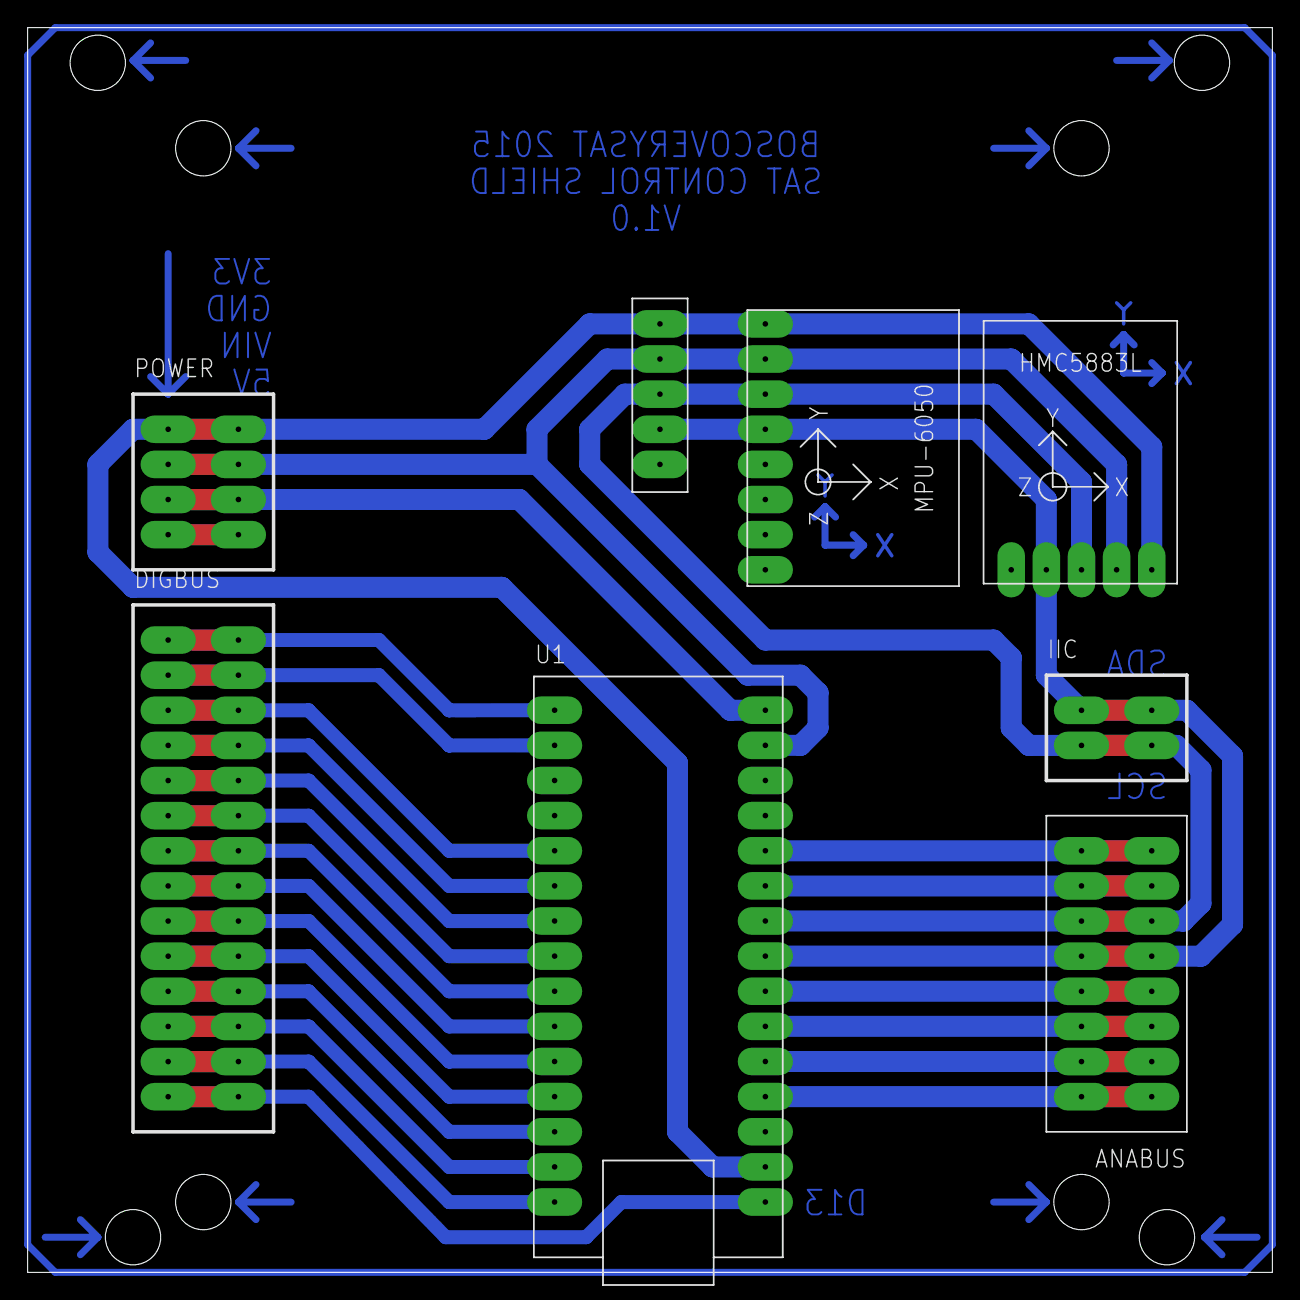
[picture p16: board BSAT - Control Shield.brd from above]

Board: 2 copper layers, 90.0 x 90.0 mm, 8 parts (0 on the bottom side), 25 nets.

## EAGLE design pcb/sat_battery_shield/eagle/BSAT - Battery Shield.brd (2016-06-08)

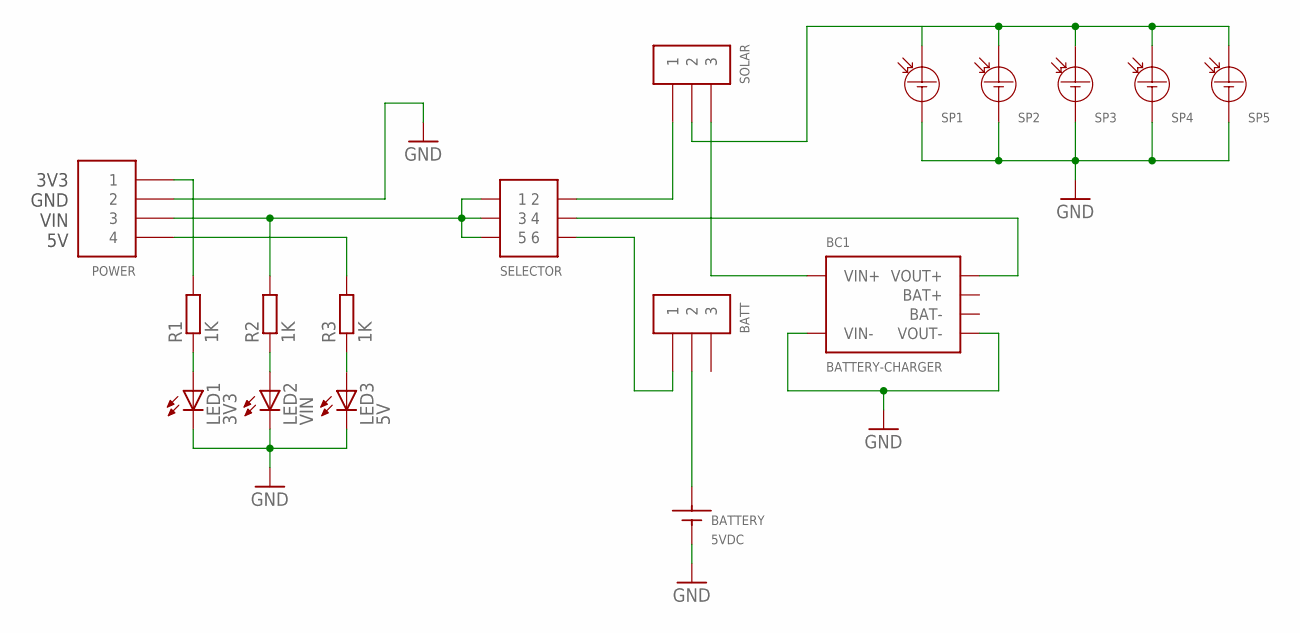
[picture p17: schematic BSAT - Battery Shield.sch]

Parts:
5VDC: BATTERY; SOLAR-PANEL
BATT: 3-PIN-JUMPER
BC1: BATTERY-CHARGER
LED1: 3V3; LED3MM
LED2: VIN; LED3MM
LED3: 5V; LED3MM
POWER: 4-PIN-DUAL-BUS; 4-PIN-LINEAL-JUMPER
R1, R2, R3: 1K; 0207/12
SELECTOR: 3-PIN-PARALEL-JUMPER
SOLAR: 3-PIN-JUMPER
SP1, SP2, SP3, SP4, SP5: SOLAR-PANEL2; SOLAR-PANEL

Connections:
GND: 5VDC.NEG, BC1.VIN-, BC1.VOUT-, LED1.K (C), LED2.K (C), LED3.K (C), POWER.2A (2), POWER.2B (2), SP1.NEG, SP2.NEG, SP3.NEG, SP4.NEG, SP5.NEG
unnamed: SELECTOR.2, SOLAR.1
unnamed: SOLAR.2, SP1.POS, SP2.POS, SP3.POS, SP4.POS, SP5.POS
unnamed: BC1.VIN+, SOLAR.3
unnamed: BC1.VOUT+, SELECTOR.4
unnamed: BATT.1, SELECTOR.6
unnamed: 5VDC.POS, BATT.2
unnamed: LED1.A, R1.1
unnamed: POWER.3A (3), POWER.3B (3), R2.2, SELECTOR.1, SELECTOR.3, SELECTOR.5
unnamed: LED2.A, R2.1
unnamed: LED3.A, R3.1
unnamed: POWER.1A (1), POWER.1B (1), R1.2
unnamed: POWER.4A (4), POWER.4B (4), R3.2

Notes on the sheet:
3V3 GND VIN 5V

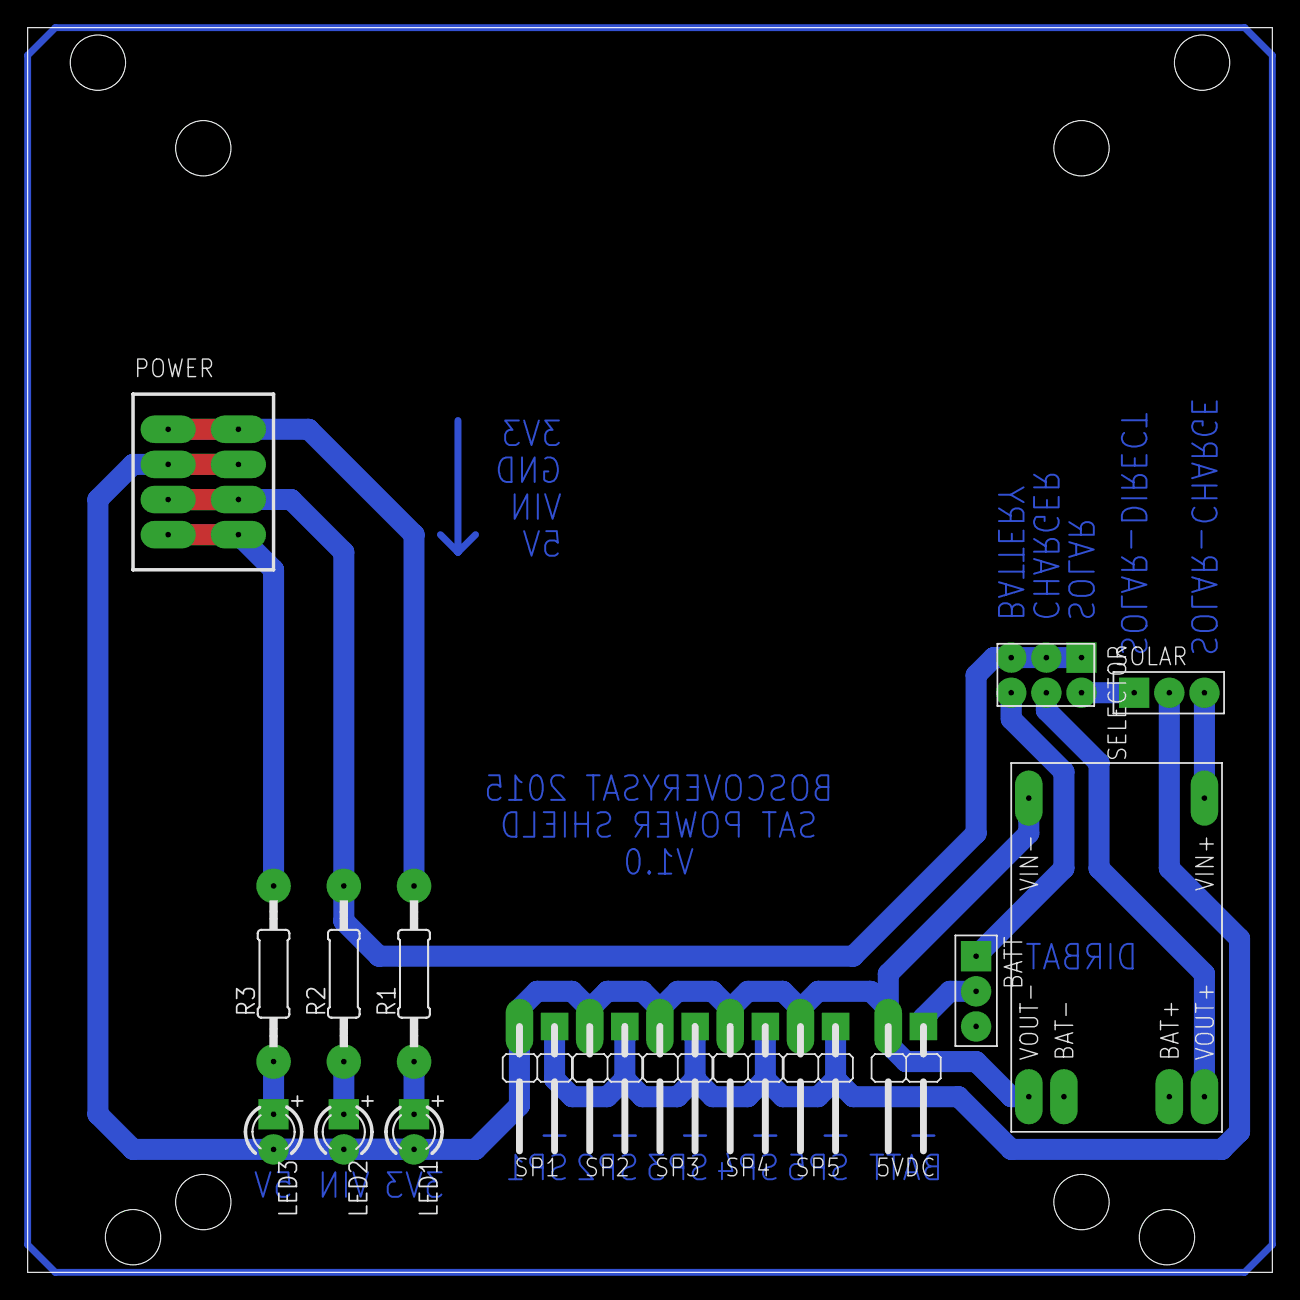
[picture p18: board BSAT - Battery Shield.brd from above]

Board: 2 copper layers, 90.0 x 90.0 mm, 17 parts (0 on the bottom side), 13 nets.

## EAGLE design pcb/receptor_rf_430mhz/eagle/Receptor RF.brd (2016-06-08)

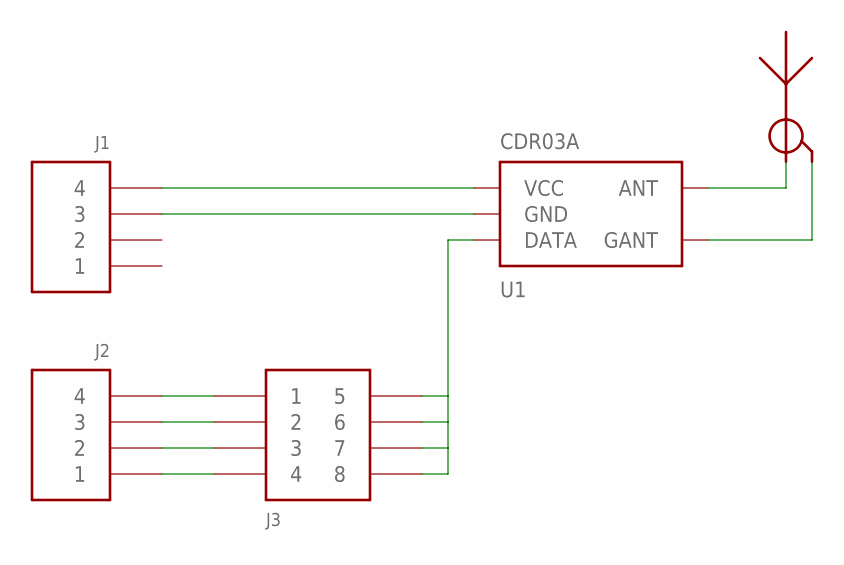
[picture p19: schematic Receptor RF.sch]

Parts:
J1, J2: 4-PIN-LINEAR-JUMPER
J3: 8-PIN-JUMPER
U1: CDR03A
U$3: ANTENNA

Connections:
unnamed: J1.P$4 (4), U1.VCC
unnamed: J1.P$3 (3), U1.GND
unnamed: J2.P$4 (4), J3.P$1 (1)
unnamed: U1.ANT, U$3.ANT
unnamed: U1.GANT, U$3.GANT
unnamed: J2.P$3 (3), J3.P$2 (2)
unnamed: J2.P$2 (2), J3.P$3 (3)
unnamed: J2.P$1 (1), J3.P$4 (4)
unnamed: J3.P$5 (5), J3.P$6 (6), J3.P$7 (7), J3.P$8 (8), U1.DATA1 (DATA), U1.DATA2 (DATA)

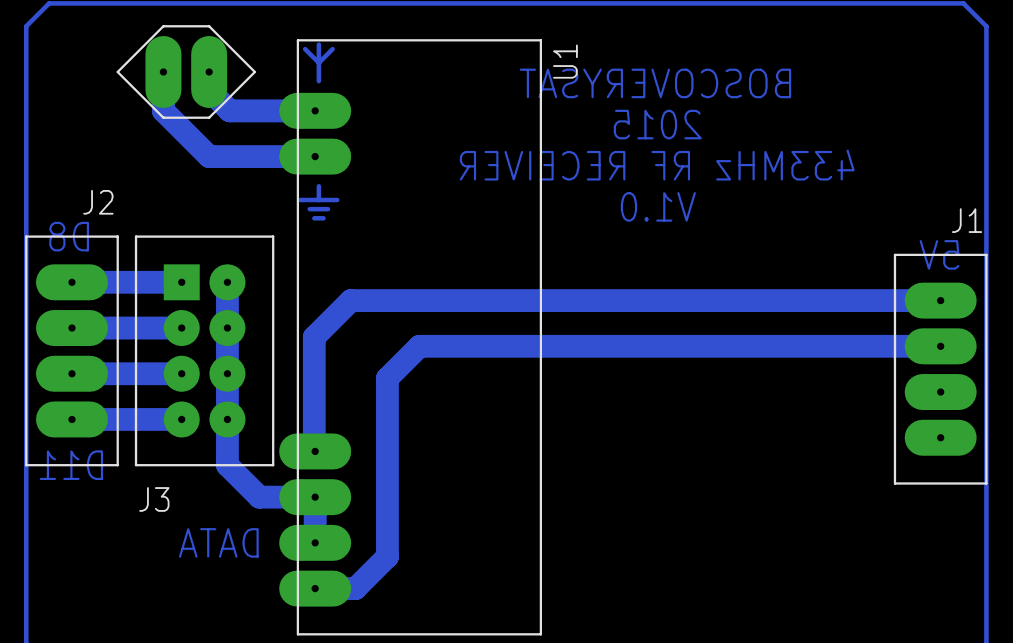
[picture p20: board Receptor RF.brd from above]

Board: 2 copper layers, 5 parts (0 on the bottom side), 9 nets.

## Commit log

2016-06-08 feat(receptor-rf-430mhz): Diseño del receptor de pruebas realizado.
    [Receptor RF.brd, Receptor RF.sch]
2016-06-08 feat(battery-shield): Diseño del módulo de alimentación realizado.
    [BSAT - Battery Shield.brd, BSAT - Battery Shield.sch]
2016-06-08 feat(battery-shield): Diseño del módulo de control realizado.
    [BSAT - Control Shield.brd, BSAT - Control Shield.sch]
2016-06-08 feat(battery-shield): Diseño del módulo de transmisiones realizado.
    [BSAT - Transmission Shield.brd, BSAT - Transmission Shield.sch]
2016-06-08 docs(battery-shield): Añadidos documentos de guía y datasheets al repositorio.
2016-06-08 feat(kicad-bsat-lib): Creada la librería de componentes electrónicos para KiCAD, empleados en el satélite.
2016-06-08 feat(battery-shield): Rediseño de la placa mediante el programa KiCAD.
    [BSAT - Battery Shield.kicad_pcb, BSAT - Battery Shield.sch]
2016-06-08 feat(control-shield): Rediseño de la placa mediante el programa KiCAD.
    [BSAT - Control Shield.kicad_pcb, BSAT - Control Shield.sch]
2016-06-11 docs(datasheet): Datasheet de los componentes NDS8435 y NEC-PS2911-1 añadidos.
2016-06-11 feat(kicad-bsat-lib): Componentes NDS8435 y NEC-PS2911-1 añadidos.
2016-06-11 feat(battery-shield): Esquema reorganizado y optoacoplador añadido para el enable/disable del cargador.
    [BSAT - Battery Shield.sch]
2017-02-07 refactor(battery-shield): Rediseño de la placa empleando el regulador de carga MAX1873.
    [BSAT - Battery Shield.sch, _saved_BSAT - Battery Shield.sch]
2017-02-07 refactor(control-shield): Rediseño de la placa y corrección de error en la conmutación entre sensores de intensidad luminosa.
    [BSAT - Control Shield.kicad_pcb, BSAT - Control Shield.sch]
2017-02-08 chore(battery-shield): Organizar archivos del diseño.
    [BSAT - Battery Shield.sch]
2017-02-08 chore(control-shield): Actualizar el diseño de pads para los componentes de la control-shield.
    [BSAT - Control Shield.sch, _saved_BSAT - Battery Shield.sch]
2017-05-13 refactor(control-shield): Rediseñar el diagrama de pistas para obtener una placa de doble cara.
    [BSAT - Control Shield.kicad_pcb]
2017-05-13 feat(control-shield): Generar los archivos Gerber para el fresado de la placa de control.
    [BSAT - Control Shield - BOTTOM.drl, BSAT - Control Shield - TOP.drl, BSAT - Control Shield-B.Cu.gbr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]
2017-05-13 feat(control-shield): Generar los archivos GCode para el fresado de la placa de control.
2017-05-14 docs(readme): Actualizar el contenido del archivo README.md.
